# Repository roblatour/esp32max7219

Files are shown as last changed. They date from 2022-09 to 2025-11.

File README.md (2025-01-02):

# ESP32 Max7219
Voice controlled scrolling message board
by Rob Latour

Notes:

   Before compiling and uploading to your ESP32, please review the key_settings.h file and make updates as you may like.

   The user's WiFi Network name (SSID), Wifi password, and Pushbullet Access Token are not stored in this sketch nor the key_settings.h file.
   Rather they are stored in non-volatile memory after being entered by the user via a web browser (see below).

To operate:

  1. Press and hold the external button for more than 10 seconds when the esp32 is powered on to trigger the process to reset your Wifi Credentials
     This should be done for initial setup, but may be done anytime afterwards if your Wifi Network name (SSID) or Wifi password change

     1.1 The message board will prompt you to take three steps (which you can do this from your computer or cell phone):
         Step 1:  connect to Wifi network ScrollingMessageBoard
	     Step 2:  open your browser in Incognito mode 
         Step 3:  browse to http://123.123.123.123
         Step 4:  enter your Wifi network information, and click 'OK'

  2. Once connected to your Wifi network:

     2.1 Press and hold the external button for 1 second to have the scrolling message board display the web address at which you can change/clear the text on the scrolling message board
         for example:  http://192.168.1.100

     2.3 (Optional) To enter a password for updating the message on the Scrolling Message Board, browse to the address identified in step 2.1 with "/password" (without the quotes) added after it,
         for example:  http://192.168.1.100/password
         To start, the current password is blank, that is to say nothing is entered in the current password box
         If the current password is changed from being blank to something else, it can later be changed back to being blank by leaving the new and confirmed new passwords as blank when updating the password
         If the current password is not blank, the user will need to enter it to to change the text of the scrolling message board via the web interface (see 2.4 below)

     2.3 (Optional) To enter your Pushbullet Access Token, browse to the address identified in step 2.1 with "/pushbullet" (without the quotes) added after it,
         for example:  http://192.168.1.100/pushbullet
         For more information on Pushbullet setup please see: https://hackaday.io/project/170281-voice-controlled-scrolling-message-board

     2.4 To change the text on the scrolling message board

         Method 1: browse to the address identified in step 2.1 above, enter the new text, and click 'OK'

         Method 2: send a Pushbullet push with the text you would like displayed

         For both methods, here are some special messages (without the quotes) you can use to have special functions performed, 
		 these are:

                   "Clear the message board"                  (clears the message board's display)
                   "Restart the message board"                (restarts the message board)
                   "Clear the memory of the message board"    (clears the non-volatile memory in which the Wifi SSID, 
				                                              Wifi Password, Pushbullet Access Token, and current
 															  message values are stored)
															  
         For Method 1, an additional method exists, it is:
                   "Show uptime"                              (this will show in the browser the amount of time since the Scrolling Message Board was last started)

         Notes: 

            the above special commands are not case sensitive; i.e.  "Show uptime" (without the quotes) and "show uptime" (without the quotes) will work equally as well

            the maximum text message length is about 4,000 characters (which should be more that enough for most use cases)

     2.5 To clear the text on the message board:

         method 1:  Press and hold the external button for more than 5 seconds

         method 2:  Click the clear button on the web page identified in 2.1 above

         method 3:  as described above, send a Pushbullet push with the message "Clear the memory of the message board" (without the quotes)

 Final Notes:

     If you are using Pushbullet, please note the two certificates stored in the pushbulletCertificates.h file
	 both have expiry dates (as shown in the file)

     I will endeavor to update this file on Github in the future but there is more information on how you can
	 do this yourself in the pushbulletCertificates.h file
	 
     When the certificates expire they will need to be updated and this sketch recompiled and reloaded

     Edit: Jan 2nd, 2025
     I've just released this program to make this super easy
     https://github.com/roblatour/certifiable

     with it just use
     certifiable api.pushbullet.com -n 2 -c
     and 
     certifiable zebra.pushbullet.com -n 2 -c
     to get the needed code copied to your Windows clipboard.

For more information please see:
https://hackaday.io/project/170281-voice-controlled-scrolling-message-board

## Support

[buy me a coffee](https://www.buymeacoffee.com/roblatour)

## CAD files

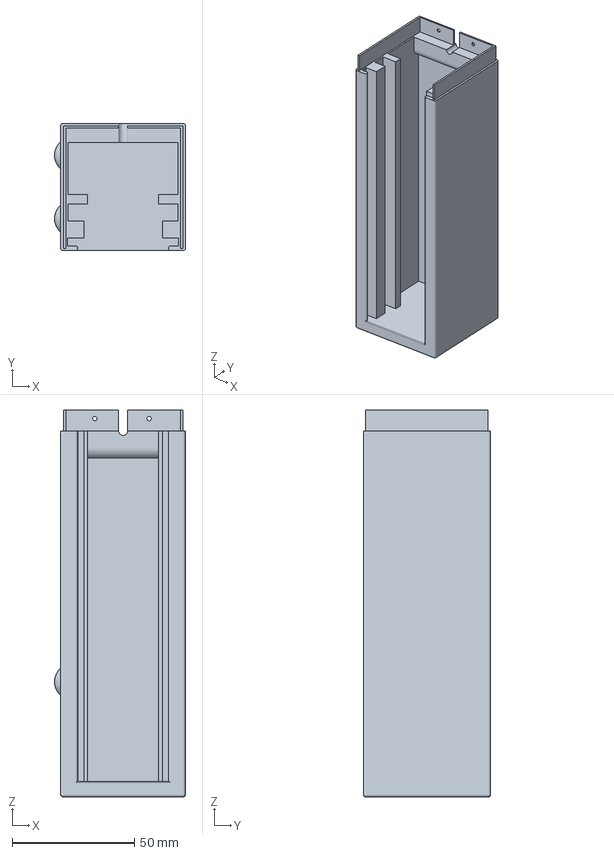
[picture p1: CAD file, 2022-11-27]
3D Printed cases/For when 13 modules are used/Max7219 Box - 3 Piece - 13 modules - RIGHT - Final v41.3mf
53.5 x 52.0 x 158.0 mm

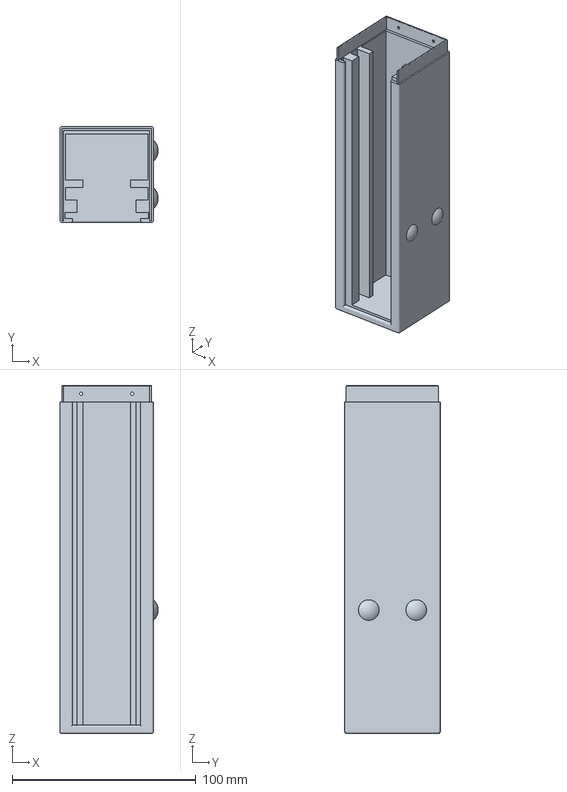
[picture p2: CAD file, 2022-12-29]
3D Printed cases/For when 16 modules are used/Max7219 Box - 3 Piece - 16 modules - LEFT - Final v4.3mf
53.5 x 52.0 x 189.2 mm

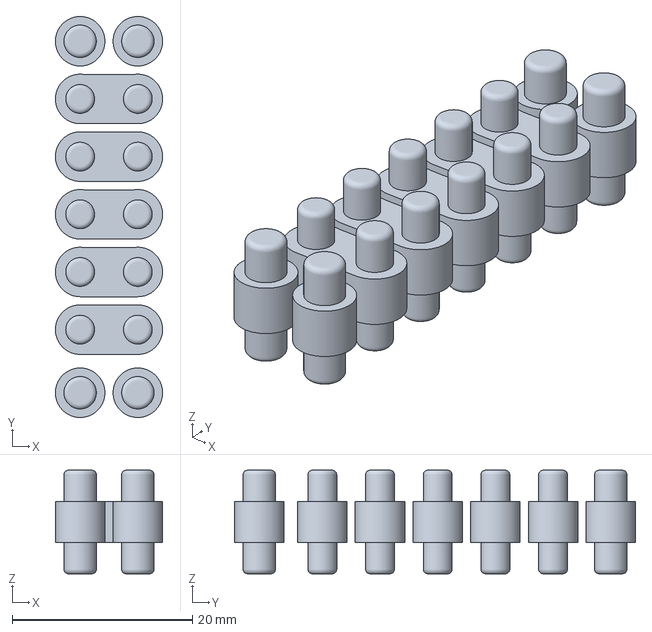
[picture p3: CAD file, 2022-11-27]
3D Printed cases/Seperators/seperators v5.3mf
11.9 x 44.5 x 11.5 mm

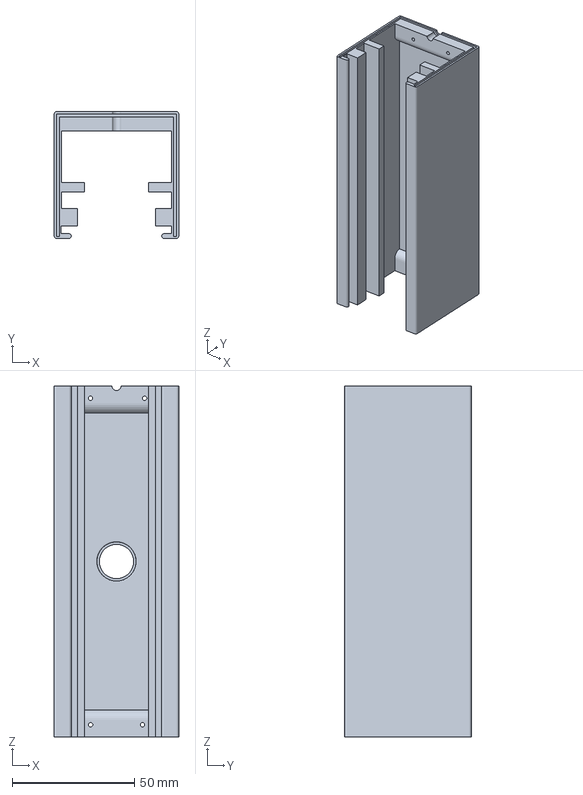
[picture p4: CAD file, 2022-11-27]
3D Printed cases/For when 13 modules are used/Max7219 Box - 3 Piece - 13 modules - MIDDLE - Final v41.3mf
51.0 x 52.0 x 143.7 mm

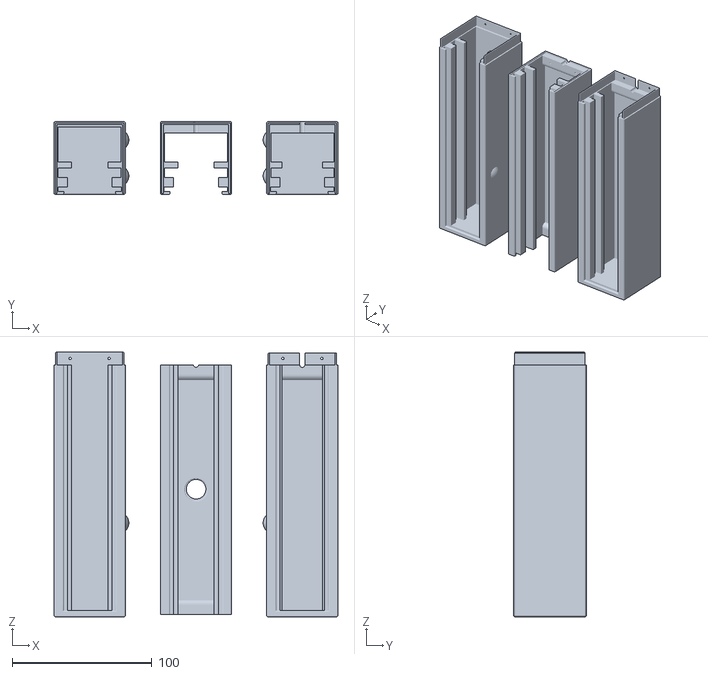
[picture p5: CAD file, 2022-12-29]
3D Printed cases/For when 16 modules are used/Max7219 Box - 3 Piece - 16 modules - Final v4.stl
203.0 x 52.0 x 189.2

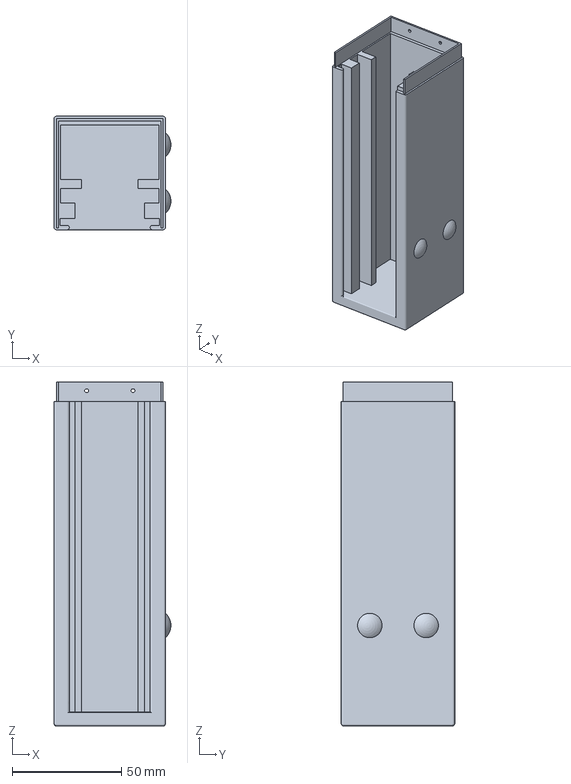
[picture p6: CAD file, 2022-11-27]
3D Printed cases/For when 13 modules are used/Max7219 Box - 3 Piece - 13 modules - LEFT - Final v41.3mf
53.5 x 52.0 x 157.5 mm

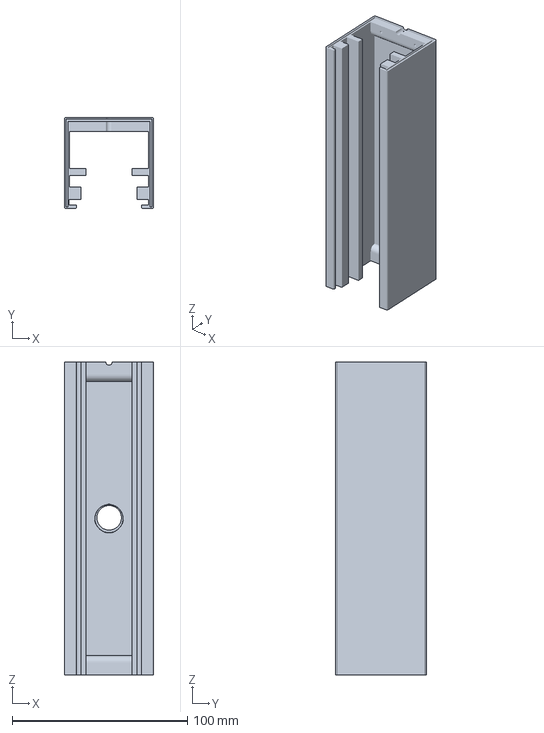
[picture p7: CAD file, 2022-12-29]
3D Printed cases/For when 16 modules are used/Max7219 Box - 3 Piece - 16 modules - MIDDLE - Final v4.3mf
51.0 x 52.0 x 178.7 mm

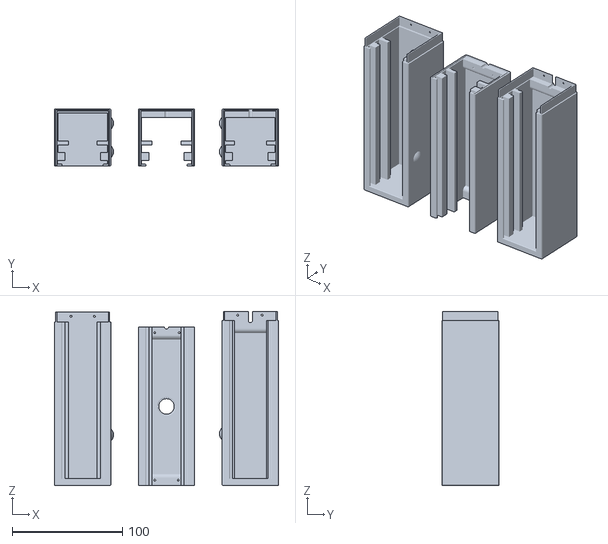
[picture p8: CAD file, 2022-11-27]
3D Printed cases/For when 13 modules are used/Max7219 Box - 3 Piece - 13 modules - Final v41.stl
203.0 x 52.0 x 158.0

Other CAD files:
3D Printed cases/For when 16 modules are used/Max7219 Box - 3 Piece - 16 modules - RIGHT - Final v4.3mf
3D Printed cases/Seperators/seperators v5.f3d
3D Printed cases/Seperators/seperators v5.stl

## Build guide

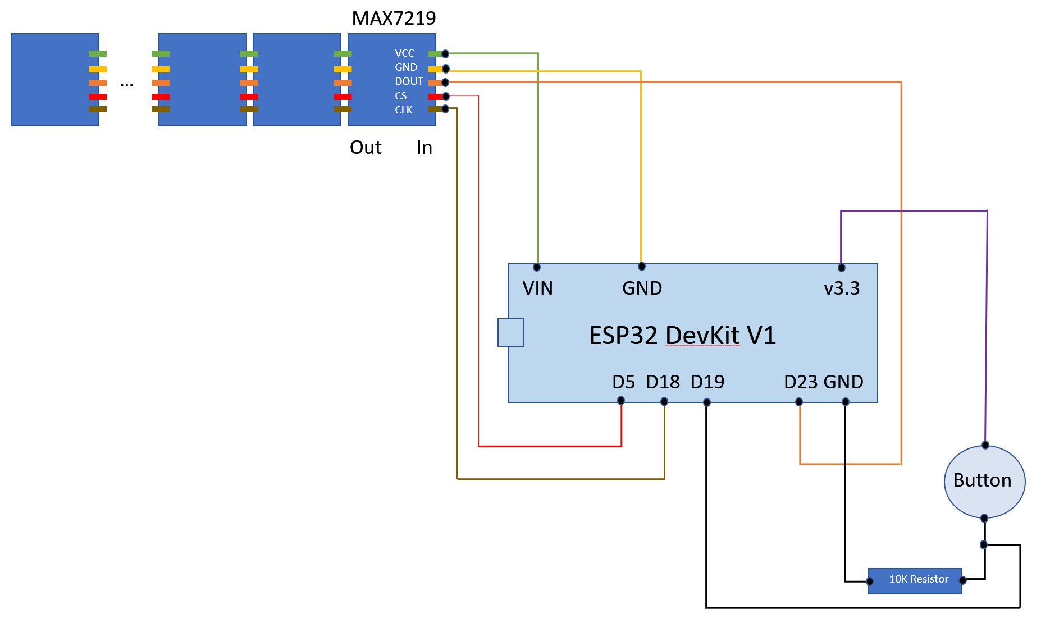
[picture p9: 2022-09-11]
Misc/wiring diagram.jpg

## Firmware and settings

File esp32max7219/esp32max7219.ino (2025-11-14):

// ESP32 Message Board v2.6
// Copyright Rob Latour, 2025 - MIT License
//
// ref: https://hackaday.io/project/170281-voice-controlled-scrolling-message-board
// ref: https://github.com/roblatour/esp32max7219
//
// Notes:
//
//   Before compiling and uploading to your ESP32, please review the key_settings.h file and make updates as you may like.
//
//   The user's WiFi Network name (SSID), Wi-Fi password, and Pushbullet Access Token are not stored in this sketch nor the key_settings.h file.
//   Rather they are stored in non-volatile memory after being entered by the user via a web browser (see below).
//
// To operate:
//
//  1. Press and hold the external button for more than 10 seconds when the esp32 is powered on to trigger the process to reset your Wi-Fi Credentials
//     This should be done for initial setup, but may be done anytime afterwards if your Wi-Fi Network name (SSID) or Wi-Fi password change
//
//     1.1 The message board will prompt you to take three steps (which you can do this from your computer or cell phone):
//         Step 1:  connect to Wi-Fi network ScrollingMessageBoard
//         Step 2:  open your browser in Incognito mode
//         Step 3:  browse to http://123.123.123.123
//         Step 4:  enter your Wi-Fi network information, and click 'OK'
//
//  2. Once connected to your Wi-Fi network:
//
//     2.1 Press and hold the external button for 1 second to have the scrolling message board display the web address at which you can change/clear the text on the scrolling message board
//         for example:  http://192.168.1.100
//
//     2.3 (Optional) To enter a password for updating the message on the Scrolling Message Board, browse to the address identified in step 2.1 with "/password" (without the quotes) added after it,
//         for example:  http://192.168.1.100/password
//         To start, the current password is blank, that is to say nothing is entered in the current password box
//         If the current password is changed from being blank to something else, it can later be changed back to being blank by leaving the new and confirmed new passwords as blank when updating the password
//         If the current password is not blank, the user will need ao enter it to to change the text of the scrolling message board via the web interface (see 2.4 below)
//
//     2.3 (Optional) To enter your Pushbullet Access Token, browse to the address identified in step 2.1 with "/pushbullet" (without the quotes) added after it,
//         for example:  http://192.168.1.100/pushbullet
//         For more information on Pushbullet setup please see: https://hackaday.io/project/170281-voice-controlled-scrolling-message-board
//
//     2.4 To change the text on the scrolling message board
//
//         Method 1: browse to the address identified in step 2.1 above, enter the new text, and click 'OK'
//
//         Method 2: send a Pushbullet push with the text you would like displayed
//
//         For both methods, here are some special messages (without the quotes) you can use to have special functions performed, these are:
//
//                   "Clear the message board"                  (this clears the message board's display)
//                   "Restart the message board"                (this restarts the message board)
//                   "Clear the memory of the message board"    (this clears the non-volatile memory in which your settings Wi-Fi SSID, Wi-Fi Password, Pushbullet Access Token, and current message are stored)
//
//         For Method 1, an additional method exists, it is:
//                   "Show uptime"                              (this will show in the browser the amount of time since the Scrolling Message Board was last started)
//
//          Notes:
//
//             the above special commands are not case sensitive; i.e.  "Show uptime" (without the quotes) and "show uptime" (without the quotes) will work equally as well
//
//             the maximum text message length is about 4,000 characters (which should be more that enough for most use cases)
//
//             if the message starts with "[1]" (without the quotes) it will appear only once
//
//     2.5 To clear the text on the message board:
//
//         method 1:  Press and hold the external button for more than 5 seconds
//
//         method 2:  Click the clear button on the web page identified in 2.1 above
//
//         method 3:  as described above, send a Pushbullet push with the message "Clear the memory of the message board" (without the quotes)
//
//
// Final Notes:
//
//     If you are using Pushbullet, please note the two certificates stored in the pushbulletCertificates.h file both have expiry dates (as shown in the file)
//
//     I will endeavor to update this file on Github in the future but there is more information on how you can do this yourself in the pushbulletCertificates.h file
//     When the certificates expire they will need to be updated and this sketch recompiled and reloaded
//
//     I am already thinking of ways to make this more seamless in the future ... perhaps a future update?
//
//     Donations welcome at https://github.com/roblatour/esp32max7219

//
// Board Manager: esp32 By Espressif Systems - version 2.0.11
//                DOIT ESP32 DEVKIT V1
//
//  Tools:
//  Core Level Debug:                      None
//  Erase all flash before sketch upload:  Disabled
//  Flash frequency:                       80MHz
//  Upload speed:                          92160
//
// Libraries:
// ArduinoJson         6.19.4 Benoit Blanchon https://arduinojson.org/?utm_source=meta&utm_medium=library.properties
// ArduinoOTA          2.0.0  (native to the Arduino IDE libraries)
// ArduinoSort         1.0.0  Emil Vikström https://github.com/emilv/ArduinoSort
// AsyncTCP            1.1.4  dvarrel https://github.com/dvarrel/AsyncTCP
// EEPROM              2.0.0  (native to the Arduino IDE libraries)
// ESP Async WebServer 2.10.8 https://github.com/esphome/ESPAsyncWebServer
// ESPmDNS             2.0.0  (native to the Arduino IDE libraries)
// FS                  2.0.0  (native to the Arduino IDE libraries)
// MD_MAX72XX          3.5.1  magicDesigns https://github.com/MajicDesigns/MD_MAX72xx
// MD_Parola           3.7.3  magicDesigns https://github.com/MajicDesigns/MD_Parola
// MD_MAXPanel         1.4.0  (dependency of MD_Parole - included above)
// SPI                 2.0.0  (native to the Arduino IDE libraries)
// Time                1.6.1  Paul Stoffregen version 1.6.1 https://github.com/PaulStoffregen/Time
// Update              2.0.0  (native to the Arduino IDE libraries)
// WebSockets          2.7.1  Markus Sattler https://github.com/Links2004/arduinoWebSockets
// WiFi                2.0.0  (native to the Arduino IDE libraries)
// WiFiClientSecure    2.0.0  (native to the Arduino IDE libraries)

#include <Arduino.h>
#include <ArduinoJson.h>
#include <ESPAsyncWebServer.h>
#include <WebSocketsClient.h>
#include <MD_Parola.h>
#include <MD_MAX72xx.h>

#include <ArduinoSort.h>
#include <time.h>
#include <WiFi.h>
#include <TimeLib.h>

#include <EEPROM.h>
#include <ArduinoOTA.h>

#include "key_settings.h"
#include "pushbulletCertificates.h"

// Program ID
const String programID = "ESP32 Message Board v2.6";

// Connection Pins:
const int externalButtonPin = EXTERNAL_BUTTON_PIN;

// Pins of an ESP32 Dev Kit V1 which connect to the Max7219
const int clkPin = CLK_PIN;
const int csPin = CS_PIN;
const int dataPin = DATA_PIN;

// EEPROM stuff
#define EepromSize MAXIMUM_SIZE_OF_NON_VOLATILE_MEMORY
int maxEEPROM;

// Button stuff
bool buttonCheckUnderway = false;

const int oneSecond = 1000;

const unsigned long buttonDownThresholdForResetingNonVolatileMemory = 10 * oneSecond; // 10 seconds
bool manualResetRequested = false;

const unsigned long buttonDownThresholdForRequestingTheMessageBoardAddress = 1 * oneSecond; // 1 second
bool messageBoardsAddressRequested = false;                                                 // if you want the board's address to appear as part of the startup message, this can be initially be set to true

const unsigned long buttonDownThresholdForClearingTheMessageBoard = 5 * oneSecond; // 5 seconds
bool clearMessageRequested = false;
bool restartRequested = false;
bool EEPROMClearRequested = false;

// Max7219 stuff
const int numberOfMax7219Modules = NUMBER_OF_MAX7219_MODULES;

#define HARDWARE_TYPE MD_MAX72XX::FC16_HW
MD_Parola P = MD_Parola(HARDWARE_TYPE, csPin, numberOfMax7219Modules); // SPI config

textEffect_t scrollEffect = PA_SCROLL_LEFT;
textPosition_t scrollAlign = PA_LEFT;
int scrollSpeed = 1000;
int scrollPause = 0;
int slider_scroll_speed;

#define BUF_SIZE EepromSize + 1    // Maximum characters in a message
char curMessage[BUF_SIZE] = {" "}; // used to hold current message

// Wi-Fi credentials are not stored as literals in this sketch, rather they are stored to and loaded from non-volatile memory (the EEPROM)
String wifiSSID = "";
String wifiPassword = "";

// Time stuff
const char *primaryNTPServer = PRIMARY_TIME_SERVER;
const char *secondaryNTPServer = SECONDARY_TIME_SERVER;
const char *tertiaryNTPSever = TERTIARY_TIME_SERVER;
const char *timeZone = MY_TIME_ZONE;

char timeHour[3] = "00";
char timeMin[3] = "00";
char timeSec[3];
String timeAmPm;

unsigned long lastTimeWiFiWasConnected;
unsigned long secondsSinceStartup;
const unsigned long twoMinutes = 120000;

unsigned long nextTimeCheck = 0;
const unsigned long oneWeekFromNow = 7 * 24 * 60 * 60 * 1000;

// Special Commands
const String clearTheESP32sMemory = CLEAR_ESP32S_MEMORY_COMMAND;
const String clearTheMessageBoardCommand = CLEAR_THE_MESSAGE_BOARD_COMMAND;
const String restartCommand = RESTART_COMMAND;
const String showUptime = SHOW_UPTIME_COMMAND;

// Pushbullet
String pushbulletAccessToken = "";
String lastPbAccessToken = "";

const String pushbulletTitleToReactTo = PUSHBULLET_TITLE_TO_REACT_TO;

String pushbulletServer = "stream.pushbullet.com";
String pushbulletServerDirectory = "/websocket/";
const String pushbulletKeepAliveID = "rob_messages_active"; // <*** do not change this, it is a special code Pushbullet has provided for use with this program only; used to prevent accounts from expiring for 30 days

bool pushbulletIsEnabled = false;
const int lengthOfAValidPushbulletAccessToken = 34;

String myPushbulletClientID = "";

bool sendPushbulletKeepAliveRequest = SEND_PUSHBULLET_KEEP_ALIVE_REQUEST;

bool alwaysConfirmStatus = false;
bool reportViaPush = false;

unsigned long startupTime;
unsigned long lastTimePushbulletWasHeardFrom;
unsigned long lastKeepAliveRequest;

const unsigned long rebootAfterThisManySecondsWithoutHearingFromPushbullet = REBOOT_AFTER_THIS_MANY_MINUTES_WITHOUT_HEARING_FROM_PUSHBULLET * 60 * oneSecond; // measured in milliseconds
const unsigned long twentyFourHours = 86400;                                                                                                                  // 24 hours * 60 minutes * 60 seconds (measured in seconds)

unsigned long secondsSinceLastKeepAliveRequest;

WebSocketsClient webSocket;

// WiFi Access Point
const char *accessPointSSID = ACCESS_POINT_SSID;
IPAddress accessPointIPAddr(123, 123, 123, 123);
IPAddress accessPointIPMask(255, 255, 255, 0);
AsyncWebServer accessPointServer(80);
AsyncEventSource accessPointevents("/events");

String availableNetworks = "";
String lastSSIDSelected = "";
String lastPasswordUsed = "";

// Intranet Web interface stuff
AsyncWebServer server(80);
AsyncEventSource events("/events");

const char *hostName = "admin";

const char *PARAM_INPUT_SSID = "ssid";
const char *PARAM_INPUT_PASSWORD = "password";

const String nothingWasEntered = "**null**";

String inputSSID = nothingWasEntered;
String inputPassword = nothingWasEntered;

String currentMessage = "";
String currentMessageTimeAndDate = "";
String currentSSID = "";
String currentPassword = "";
String currentPBAccessToken = "";

String htmlFriendlyCurrentMessage = "";
String htmlFriendlyFeedbackColor = "black";
String htmlFriendlyFeedback = "";

String messageboardPassword = "";

// note: in the htmlHeader the .form-action style is added to cause the button order to be reversed when presented.
// this is used on the htmlDataEntryWindow to make the right most button (the 'Update' button) the default sumbit button.
// without this the left most button would be the default submit button.

const char htmlHeader[] PROGMEM = R"rawliteral(<!DOCTYPE html>
<html>
<head>
<meta name="viewport" content="width=device-width, initial-scale=1">
<style>
 body { background: #555; }
 .content {
   max-width: 500px;
   margin: auto;
   background: white;
   padding: 10px;
   word-wrap: break-word;
 }
 .form-actions {
  display: flex;
  flex-direction: row-reverse; /* reverse the elements inside */
  justify-content: center;
  align-items: center;
}
</style>
</head>
<body>
<div class="content"> 
  <h1><center>Scrolling Message Board</center></h1>
  <p>
    <form action="/get">
      <center>
)rawliteral";

const char htmlFooter[] PROGMEM = R"rawliteral(
     </center>
    </form>    
  </p>
</div>
<script>
       window.history.replaceState('','','/');
</script>
</body>
</html>
)rawliteral";

// if you would rather the 'include time and date' checkbox set to checked as a default, use:
// <input type="checkbox" id="includetime" name="includetime" checked><label for="includetime">Include $time$</label><br>

const char htmlDataEntryWindow[] PROGMEM = R"rawliteral(
     Message:<br>
     <input type="text" name="message" value="$MESSAGE$" width="340" maxlength="4095"><br>
     <br>
     <input type="checkbox" id="includetime" name="includetime"><label for="includetime">Include $time$</label><br>
     <br> 
     <div name="passwordneeded">
        Update password:<br><input type="password" name="DEpassword" value="" width="340" maxlength="128"><br><br>
     </div>
     <div name="errormessages" style="color:$color$">
       $errors$
       <br>
       <br>
     </div>
     <div class="form-actions">
         <input type="submit" name="update" alt="Update" value="Update">&nbsp&nbsp&nbsp<input type="submit" name="clear" alt="Clear" value="Clear">
     </div>
)rawliteral";
const char *PARAM_INPUT_MESSAGE = "message";
const char *PARAM_INPUT_CLEAR = "clear";
const char *PARAM_INPUT_UPDATE = "update";
const char *PARAM_INPUT_DATA_ENTRY_PASSWORD = "DEpassword";
const char *PARAM_INPUT_INCLUDETIME = "includetime";

const char htmlConfirmCleared[] PROGMEM = R"rawliteral(
     The Scrolling Message Board is being cleared.<br>
     <br>
     <input type="submit" name="messageclear" alt="OK" value="OK">  
)rawliteral";
const char *PARAM_MESSAGE_CLEAR = "messageclear";

const char htmlConfirmMemoryCleared[] PROGMEM = R"rawliteral(
     The memory of the Scrolling Message Board will be cleared<br>    
     and the Scrolling Message Board restarted.<br>
     <br>
     Please close this window.  
)rawliteral";

const char htmlConfirmRestart[] PROGMEM = R"rawliteral(
     The Scrolling Message Board is being restarted.<br>
     <br>
     Please close this window.  
)rawliteral";

const char htmlConfirmUptime[] PROGMEM = R"rawliteral(
     The Scrolling Message Board has been up for<br>    
     <br>
     $uptime$<br>
     <br>
     <input type="submit" name="uptimeok" alt="OK" value="OK">  
)rawliteral";
const char *PARAM_UPTIME_OK = "uptimeok";

const char htmlConfirmUpdate[] PROGMEM = R"rawliteral(
     The Scrolling Message Board is being updated with the message:<br>
     <br>
     $MESSAGE$<br>
     <br>
     <input type="submit" name="messageconfirm" alt="OK" value="OK">
)rawliteral";
const char *PARAM_MESSAGE_CONFIRM = "messageconfirm";

const char htmlGetPushbulletCredentials[] PROGMEM = R"rawliteral(
     <br>
     Pushbullet Access Token:&nbsp<input type="password" name="pbaccesstoken" value="$pbaccesstoken$" maxlength="$99$"><br>
     <br>
     <div style="color:$color$">$errors$</div>
     <br>     
     <input type="submit" name="pbUpdate" alt="Update" value="OK"> 
)rawliteral";
const char *PARAM_INPUT_PUSHBULLET_UPDATE = "pbUpdate";
const char *PARAM_INPUT_PUSHBULLET_ACCESS_TOKEN = "pbaccesstoken";

const char htmlClearPushbulletAccessToken[] PROGMEM = R"rawliteral(
     The Pushbullet Access Token has been cleared.<br>
     <br>
     The Scrolling Message Board is being restarted.<br>     
     <br>
     Please close this window.    
)rawliteral";

const char htmlConfirmPushbulletAccessToken[] PROGMEM = R"rawliteral(
     The Pushbullet Access Token has been updated.<br>
     <br>
     The Scrolling Message Board is being restarted.<br>     
     <br>
     Please close this window.    
)rawliteral";

const char htmlGetMessageboardPasswordCredentials[] PROGMEM = R"rawliteral(
     <br>
     Password change for webpage updates:<br>
     <br>
     Current password:&emsp;&emsp;&ensp;<input type="password" name="old" value=""><br>
     <br>
     New password:&emsp;&emsp;&emsp;&ensp;&nbsp;<input type="password" name="new1" value=""><br>
     <br>
     Confirm new password:&ensp;<input type="password" name="new2" value=""><br>
     <br>
     <div style="color:$color$">$errors$</div>
     <br>     
     <input type="submit" name="messageboardupdate" alt="Update" value="OK"> 
)rawliteral";
const char *PARAM_INPUT_MESSAGEBOARD_PASSWORD_OLD = "old";
const char *PARAM_INPUT_MESSAGEBOARD_PASSWORD_NEW_1 = "new1";
const char *PARAM_INPUT_MESSAGEBOARD_PASSWORD_NEW_2 = "new2";
const char *PARAM_INPUT_MESSAGEBOARD_PASSWORD_UPDATE = "messageboardupdate";

const char htmlMessageboardPasswordConfirmed[] PROGMEM = R"rawliteral(
     The Message Board's web update password has been changed.<br>
     <br>     
     <input type="submit" name="messageboardupdateconfirm" alt="Update" value="OK">    
)rawliteral";
const char *PARAM_INPUT_MESSAGEBOARD_PASSWORD_UPDATE_CONFIRM = "messageboardupdateconfirm";

const char htmlGetWifiCredentials[] PROGMEM = R"rawliteral(
     <br>
     Network:&nbsp
     <select name="ssid" id="ssid">
     $options$
     </select>
     <br>
     <br>
     Password:&nbsp<input type="password" name="password" maxlength="63"><br>
     <br>     
     <div style="color:red">$errors$</div>
     <br>    
     <input type="submit" alt="Update" value="OK"> 
)rawliteral";

const char htmlConfirmWIFI[] PROGMEM = R"rawliteral(
     The Wi-Fi credentials entered are now being tested.<br>
     <br>
     If they are good, the Scrolling Message Board will automatically restart and use them from now on.<br><br>
     If in the future they change, just repeat this process by holding down the Scrolling Message Board's button for more than 10 seconds when the Scrolling Message Board is being powered on.<br>
     <br>
     If they are not good, when prompted please reconnect to the '$ACCESS POINT$' network and try again.<br>
     <br>
     Have a great day!<br>
     <br>
     Please close this webpage.<br>
     <br>
)rawliteral";

bool setupComplete = false;

void setupSerial()
{

  Serial.begin(115200);
  delay(1000);
  Serial.println("");
  Serial.println("Starting " + programID);
}

bool getNTPTime()
{

  Serial.println("Getting NTP time");

  bool returnValue = false;

  struct tm timeinfo;

  if (getLocalTime(&timeinfo))
  {
    time_t t = mktime(&timeinfo);
    struct timeval now = {.tv_sec = t};
    settimeofday(&now, NULL);
    Serial.printf("Time set to: %s", asctime(&timeinfo));
    Serial.println();
    returnValue = true;
  };

  return returnValue;
}

void setupTime()
{

  const unsigned long oneWeekFromNow = 7 * 24 * 60 * 60 * 1000;

  Serial.println("Setting time ... ");

  bool timeWasSuccessfullySet = false;

  configTime(0, 0, primaryNTPServer, secondaryNTPServer, tertiaryNTPSever);
  setenv("TZ", timeZone, 1);
  tzset();

  timeWasSuccessfullySet = getNTPTime();

  if (!timeWasSuccessfullySet)
  {

    Serial.println("Time could not be set from NTP server");

    const int epochYear = 1900;
    const int monthOffset = 1;

    struct tm timeinfo;
    timeinfo.tm_year = 2023 - epochYear;
    timeinfo.tm_mon = 1 - monthOffset;
    timeinfo.tm_mday = 1;
    timeinfo.tm_hour = 00;
    timeinfo.tm_min = 00;
    timeinfo.tm_sec = 00;

    time_t t = mktime(&timeinfo);
    struct timeval now = {.tv_sec = t};
    settimeofday(&now, NULL);

    nextTimeCheck = millis() + oneWeekFromNow;
  };

  startupTime = millis();

  lastTimePushbulletWasHeardFrom = millis();
}

void refreshTimeOnceAWeek()
{

  if (millis() > nextTimeCheck)
  {

    const unsigned long oneWeekFromNow = 7 * 24 * 60 * 60 * 1000;
    const unsigned long oneHourFromNow = 60 * 60 * 1000;

    if (getNTPTime())
      nextTimeCheck = millis() + oneWeekFromNow;
    else
      nextTimeCheck = millis() + oneHourFromNow;
  };
}

void resetMax7219(bool clear)
{

  P.displayReset();

  P.setTextEffect(scrollEffect, scrollEffect);
  slider_scroll_speed = map(scrollSpeed, 1023, 0, 15, 400);
  P.setSpeed(slider_scroll_speed);

  if (clear)
    P.displayClear();
}

void setupMax7219()
{

  P.begin(); // Setup Max 7219
  resetMax7219(false);
}
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
void loop()
{
  static unsigned long lastMaintenanceTime = 0;
  const unsigned long maintenanceInterval = 1000; // Run maintenance tasks every second

  // Always handle immediate user interactions and display
  checkButton();
  clearDisplayAsNeeded();
  displayMessageBoardsAddressAsNeeded();
  fullyScrollMessageOnMax();

  // Run maintenance tasks less frequently to reduce blocking
  if (millis() - lastMaintenanceTime > maintenanceInterval)
  {
    checkWifiConnection(); // Now non-blocking
    checkPushbulletConnection();
    keepPushbulletAccountAlive(false);
    refreshTimeOnceAWeek();
    restartAndClearAsNeeded();

    lastMaintenanceTime = millis();
  }

  // Handle network tasks frequently to prevent timeouts
  keepPushbulletSessionAlive();
  ArduinoOTA.handle();
};

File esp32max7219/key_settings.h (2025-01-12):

// this is a consolidation of key user settings

#define NUMBER_OF_MAX7219_MODULES                                     13                                       // Number of connected Max7219 modules

#define EXTERNAL_BUTTON_PIN                                           19                                       // External button pin used to clear message and reset the wifi credentials

#define CLK_PIN                                                       18                                       // ESP32 CLK pin
#define CS_PIN                                                        5                                        // ESP32 CS pin
#define DATA_PIN                                                      23                                       // ESP32 Data pin

#define ACCESS_POINT_SSID                                             "ScrollingMessageBoard"                  // Access Point network name

#define PUSHBULLET_TITLE_TO_REACT_TO                                  "Leave a message"
                                                                                                               // Special commands:
#define CLEAR_ESP32S_MEMORY_COMMAND                                   "Clear the memory of the message board"  // clear all non-volatile memory (i.e. current wifi SSID, wifi Password, Pushbullet Access Token, and the current message)
#define CLEAR_THE_MESSAGE_BOARD_COMMAND                               "Clear the message board"                // clear the current message 
#define RESTART_COMMAND                                               "Restart the message board"              // restart the message board
#define SHOW_UPTIME_COMMAND                                           "Show uptime"                           // show uptime in the web browser

#define MAXIMUM_SIZE_OF_NON_VOLATILE_MEMORY                            4096                                    // 4096 (4K) is the maximum supported

#define SEND_PUSHBULLET_KEEP_ALIVE_REQUEST                             true                                    // normally set to true; set to false when testing
#define REBOOT_AFTER_THIS_MANY_MINUTES_WITHOUT_HEARING_FROM_PUSHBULLET 15


#define MY_TIME_ZONE                                                   "EST5EDT,M3.2.0,M11.1.0"                // Time Zone for America/Toronto   
                                                                                                               // Supported Timezones are listed here: https://github.com/nayarsystems/posix_tz_db/blob/master/zones.csv
                                                                                                               //
#define PRIMARY_TIME_SERVER                                            "time.nrc.ca"                           // primary ntp time server
#define SECONDARY_TIME_SERVER                                          "ca.pool.ntp.org"                       // secondary ntp time server
#define TERTIARY_TIME_SERVER                                           "north-america.pool.ntp.org"            // tertiary ntp time server 
                                                                                                               // alternative ntp time servers/time server pools; 
                                                                                                               // best to use a more local server / server pool as the primary and spread out from there
                                                                                                               //    "time.nrc.ca"                  time server in Ottawa, On, Canada
                                                                                                               //    "ca.pool.ntp.org"              time server pool for Canada                                                                                                                                                                                                                                            
                                                                                                               //    "asia.pool.ntp.org"               
                                                                                                               //    "europe.pool.ntp.org"
                                                                                                               //    "north-america.pool.ntp.org" 
                                                                                                               //    "oceania.pool.ntp.org"
                                                                                                               //    "south-america.pool.ntp.org" 
                                                                                                               //    "pool.ntp.org"                  world wide time server pool
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

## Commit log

2020-03-08 create esp32max7219
2020-03-08 Create ClearMessage.bat
    an alternate way to clear the message board
    replace xxx with your Pushbullet Access Token
    requires curl be installed on your PC
2021-11-02 Update esp32max7219.ino
    update root certificate for keepalive
2021-12-13 Update esp32max7219.ino
    corrected cert for pushbullet keep alive request
    [esp32max7219.ino]
2022-09-10 Update esp32max7219.ino
    add support for a button to restart the message board
2022-09-10 Update esp32max7219.ino
    updated with improved logic in support of the reset button.
2022-09-11 Create wiring diagram.jpg
    added wiring diagram
2022-09-11 Update esp32max7219.ino
    update reset button pin to match wiring diagram
2022-09-11 Update wiring diagram.jpg
    updated wiring diagram to better show connections
2022-09-16 Update esp32max7219.ino
    Updates so allow the user to clear and restart the message board based on special phrases sent to the message board - "Clear the message board" and "Restart the message board".
2022-11-27 release of version 2
    wifi credentials entered via web interface and stored in non-volatile memory; no need to recompile.
    pushbullet acccess token entered via web interface and stored in non-volatile memory, no need to recompile.
    new web interface to update the scrolling message.
    continued support for pushbullet to update the scrolling message.
    non-volatile memory can be cleared without recompiling.
    message retained through power off.
2022-11-27 reformat folder include 3d print files
    [Max7219 Box - 3 Piece - 13 Segments - Final v41.stl, Max7219 Box - 3 Piece - 13 Segments - LEFT - Final v41.3mf, Max7219 Box - 3 Piece - 13 Segments - MIDDLE -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]
2022-11-28 minor update to make the update button on the data entry window the default
2022-12-29 added 'Show uptime' as a special command + 3D print files for a 16 module case
    [Max7219 Box - 3 Piece - 13 Segments - Final v41.stl, Max7219 Box - 3 Piece - 13 Segments - LEFT - Final v41.3mf, Max7219 Box - 3 Piece - 13 Segments - MIDDLE -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]
2022-12-29 make special commands case insensitive
2025-02-10 Update esp32max7219.ino
    added auto reconnect if the wifi connection goes down
2025-11-14 Update esp32max7219.ino
    updates for improved wifi connection
